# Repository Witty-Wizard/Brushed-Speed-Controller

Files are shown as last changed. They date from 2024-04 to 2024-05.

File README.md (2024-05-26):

<p align="center">
    
    
    
    
    
    
</p>

# Brushed Speed Controller

This project aims to create a Brushed Electronic Speed Controller (ESC) using KiCad. The ESC is designed to control the speed of a brushed DC motor using pulse-width modulation (PWM) signals.

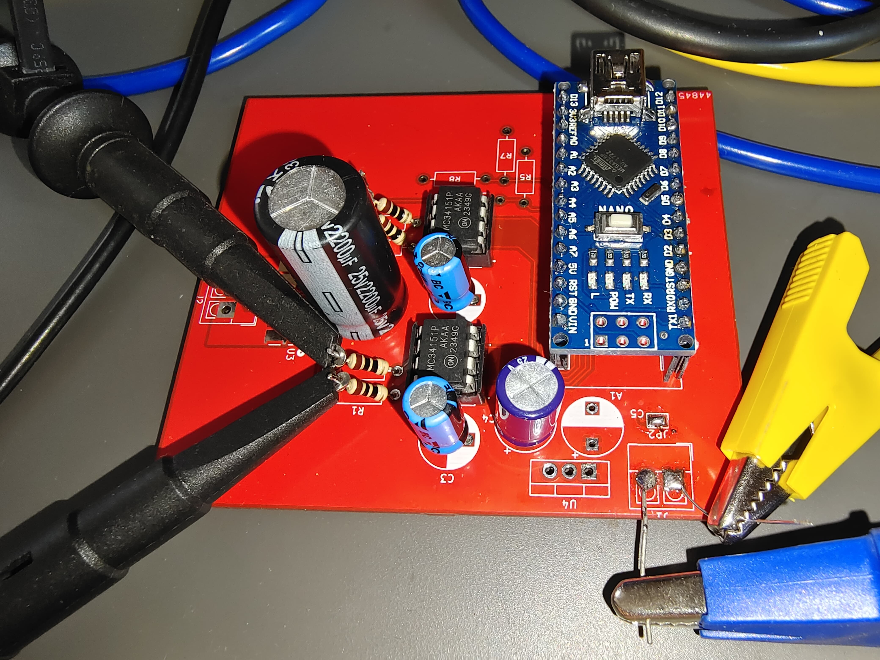
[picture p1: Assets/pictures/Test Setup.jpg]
Current Test Setup

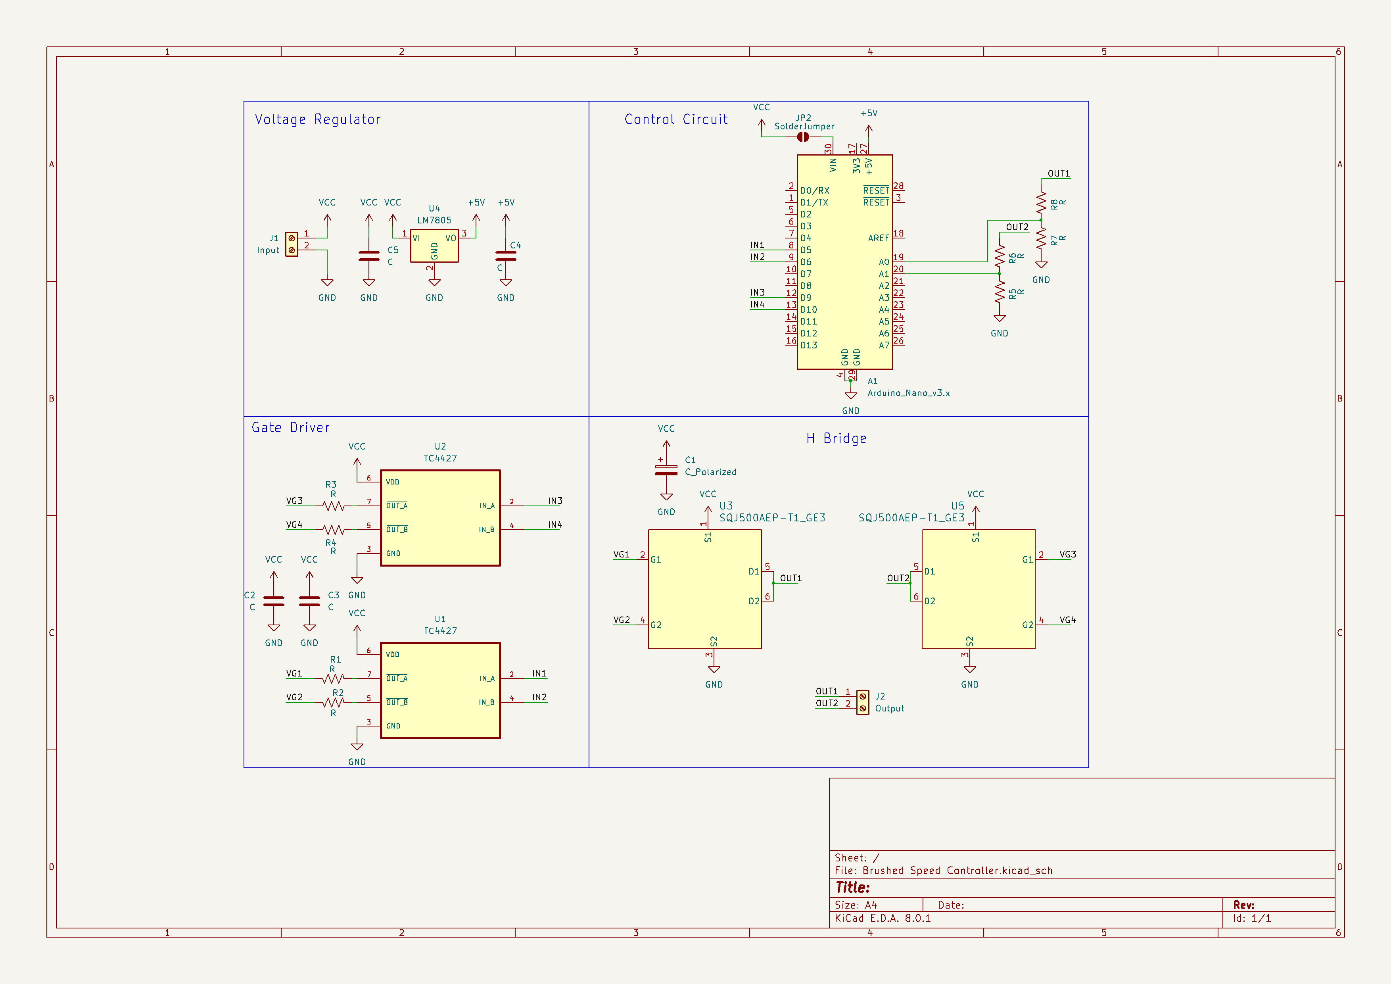
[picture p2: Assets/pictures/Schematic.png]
Schematic


## Components

### MOSFETs

- BSC340N08NS3
- ISC037N03L5ISATMA1

### Driver

- TC4427
- MC34151

### Arduino Nano

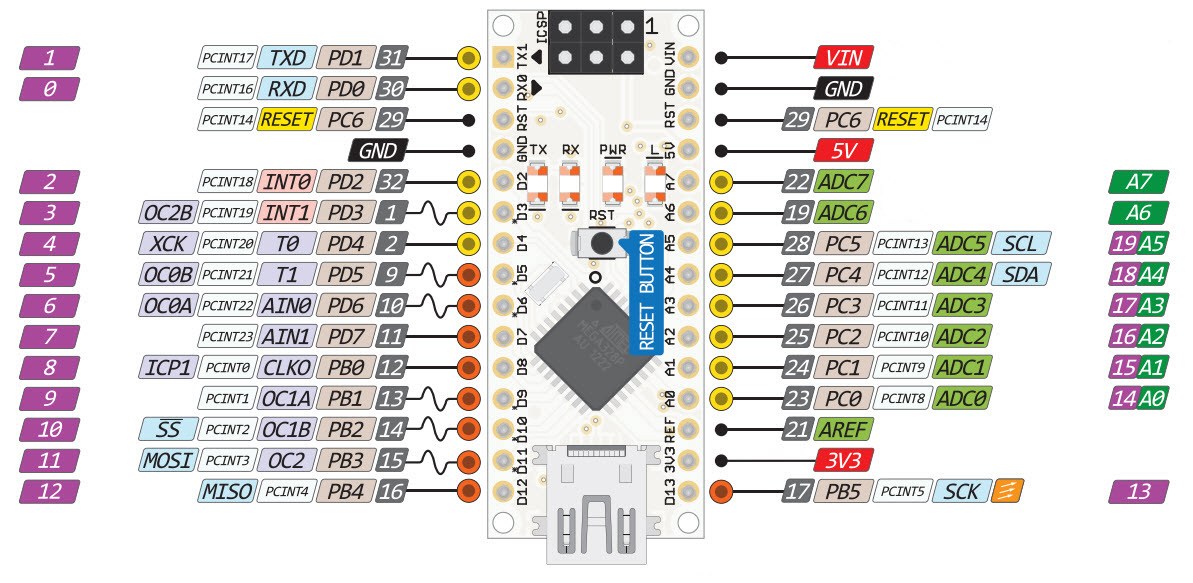
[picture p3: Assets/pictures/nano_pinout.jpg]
Arduino Pinout


### Output FSM

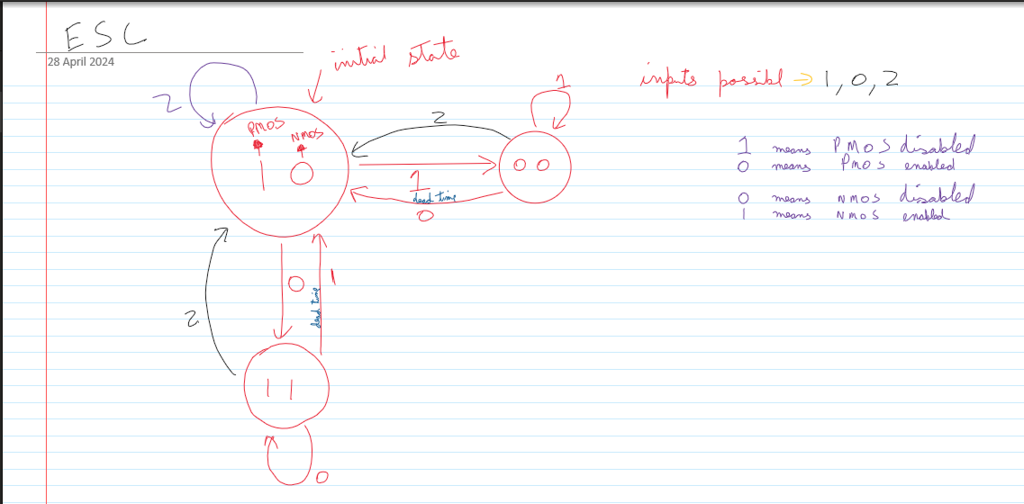
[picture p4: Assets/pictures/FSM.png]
Output side FSM logic


## Getting Started

To get started with this project, follow these steps:

1. Clone this repository to your local machine.

   ```bash
   git clone https://github.com/Witty-Wizard/Brushed-Speed-Controller.git
   ```

## License

This project is licensed under the GNU General Public License v3.0. You can find more details in the LICENSE file.

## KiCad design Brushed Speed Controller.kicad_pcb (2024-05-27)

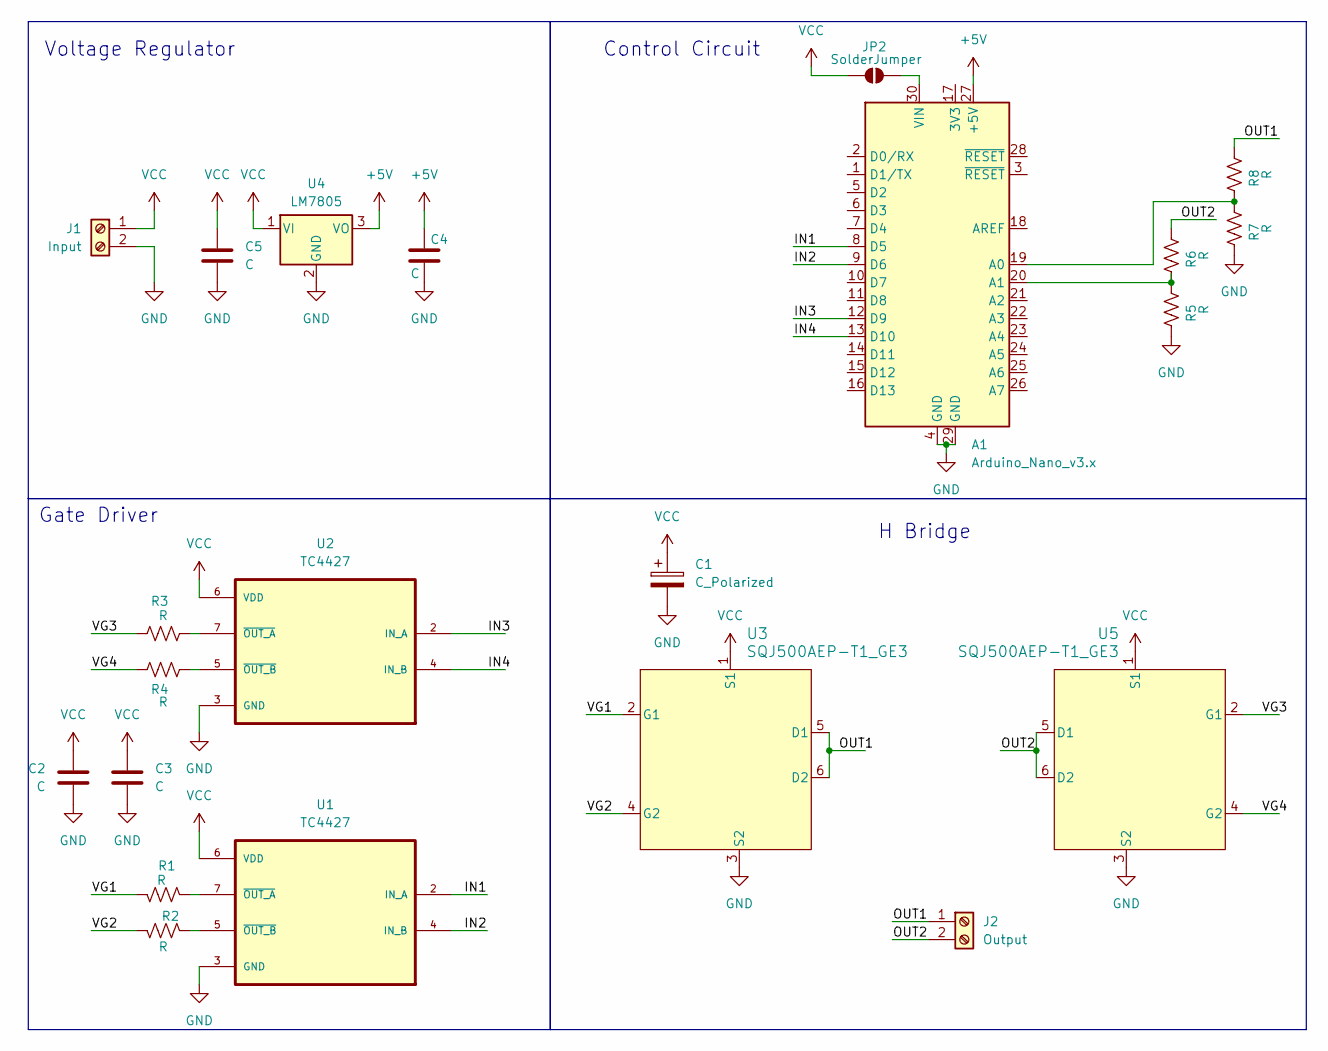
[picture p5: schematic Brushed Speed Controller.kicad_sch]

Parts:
A1: Arduino_Nano_v3.x; Arduino_Nano
C1: C_Polarized; CP_Radial_D8.0mm_P5.00mm
C2, C3, C4, C5: C; CP_Radial_D8.0mm_P5.00mm
J1: Input; TerminalBlock_bornier-2_P5.08mm
J2: Output; TerminalBlock_bornier-2_P5.08mm
JP2: SolderJumper; SolderJumper-2_P1.3mm_Open_TrianglePad1.0x1.5mm
R1, R2, R3, R4, R5, R6, R7, R8: R; R_Axial_DIN0207_L6.3mm_D2.5mm_P10.16mm_Horizontal
U1, U2: TC4427; PARTREV LTR
U3, U5: SQJ500AEP-T1_GE3; SQJ500AEP-T1-GE3
U4: LM7805; TO-220-3_Vertical

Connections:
+5V: A1.27 (+5V), C4.1, U4.3 (VO)
/IN1: A1.8 (D5), U1.2 (IN_A)
/IN2: A1.9 (D6), U1.4 (IN_B)
/IN3: A1.12 (D9), U2.2 (IN_A)
/IN4: A1.13 (D10), U2.4 (IN_B)
/OUT1: J2.1, R8.2, U3.5 (D1), U3.6 (D2)
/OUT2: J2.2, R6.2, U5.5 (D1), U5.6 (D2)
/VG1: R1.2, U3.2 (G1)
/VG2: R2.2, U3.4 (G2)
/VG3: R3.1, U5.2 (G1)
/VG4: R4.1, U5.4 (G2)
GND: A1.4 (GND), A1.29 (GND), C1.2, C2.2, C3.2, C4.2, C5.2, J1.2, R5.1, R7.1, U1.3 (GND), U2.3 (GND), U3.3 (S2), U4.2 (GND), U5.3 (S2)
unnamed: A1.19 (A0), R7.2, R8.1
unnamed: A1.20 (A1), R5.2, R6.1
unnamed: A1.30 (VIN), JP2.2 (B)
unnamed: R1.1, U1.7 (~OUT_A)
unnamed: R2.1, U1.5 (~OUT_B)
unnamed: R3.2, U2.7 (~OUT_A)
unnamed: R4.2, U2.5 (~OUT_B)
VCC: C1.1, C2.1, C3.1, C5.1, J1.1, JP2.1 (A), U1.6 (VDD), U2.6 (VDD), U3.1 (S1), U4.1 (VI), U5.1 (S1)

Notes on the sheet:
Voltage Regulator
H Bridge
Gate Driver
Control Circuit

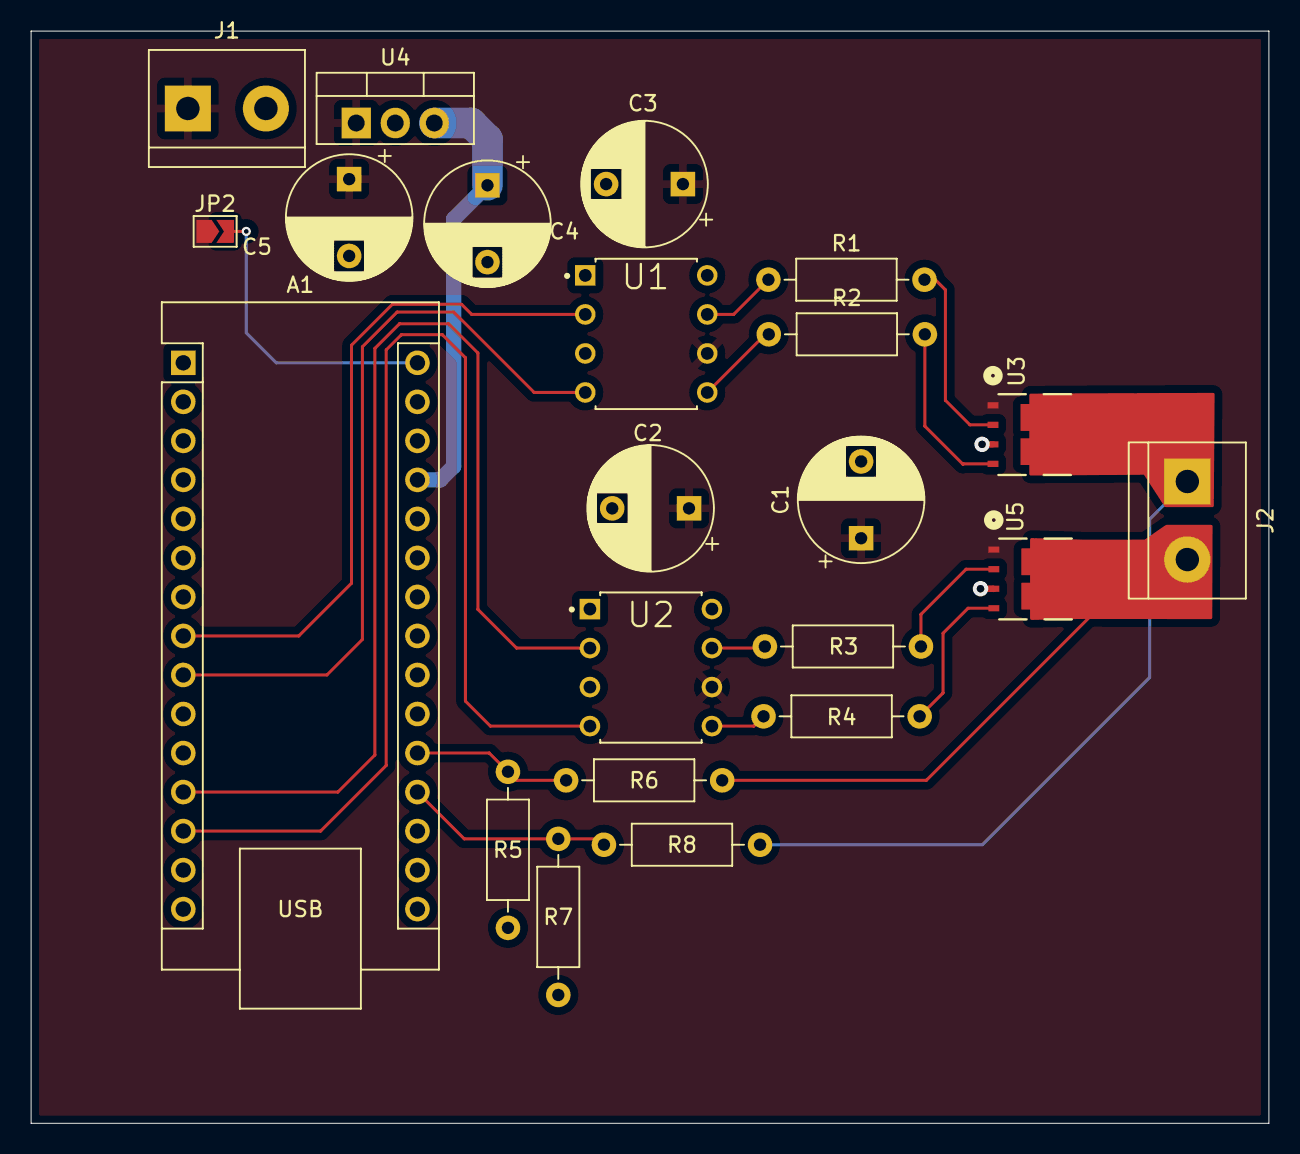
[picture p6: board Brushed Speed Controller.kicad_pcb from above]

Board: 2 copper layers, 80.6 x 71.1 mm, 22 parts (0 on the bottom side), 20 nets.

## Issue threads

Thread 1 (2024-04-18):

Use complementary P and N Mosfet for brushed ESC

Witty-Wizard, 2024-04-18:
Use the complementary N and P MOSFETs available in the SQJ500AEP-T1_GE3 for the brushed ESC design.

Witty-Wizard, 2024-04-18:
https://github.com/Witty-Wizard/Brushed-Speed-Controller/commit/bb878c7fc1ba5f598c44eacfe42a8b9dacc64ff8

Added the mosfet symbol in this commit, next need to add arduino Nano footprint

Witty-Wizard, 2024-04-25:
https://github.com/Witty-Wizard/Brushed-Speed-Controller/commit/e62d8913a873fe9dd3966c9efc68bd3aa09c23e9
@anshchawla521 Check this updated PCB

Witty-Wizard, 2024-05-26:
PCB approved by @anshchawla521 🥳🥳

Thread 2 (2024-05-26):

Use 2.54 mm Footprint of PCB terminal.

anshchawla521, 2024-05-26:
Either use 2.54 mm footprint for PCB terminal or add footprint for Xt-60.

Witty-Wizard, 2024-05-27:
https://github.com/Witty-Wizard/Brushed-Speed-Controller/commit/a9986da4f75f14f337d17ce60b3ca8d79011ef92

Closed 2024-05-27.

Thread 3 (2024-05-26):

Use of timer 0 on pin 5 ,6

anshchawla521, 2024-05-26:
Since pin 5, 6 are used for on side of h bridge we only get an 8 bit resolution since the timer 0 only supports that. This may be something to keep in mind when assigning pins for BB51

Witty-Wizard, 2024-05-27:
> Since pin 5, 6 are used for on side of h bridge we only get an 8 bit resolution since the timer 0 only supports that. This may be something to keep in mind when assigning pins for BB51

In BB51 all timers are 16-bit so no issues there

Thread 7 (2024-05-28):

🪲[Bug]: The mosfet Foot print is wrong

anshchawla521, 2024-05-28:
**Describe the bug**
The mosfet Foot print is wrong the NMOS connections are connected to PMOS and the Pmos connections are connected to NMOS

**To Reproduce**
Steps to reproduce the behavior:
NA

**Expected behavior**
NA

**Screenshots**
NA

**Desktop (please complete the following information):**
NA

**Smartphone (please complete the following information):**
NA

**Additional context**
NA

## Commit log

2024-04-16 Made H bridge
    [Brushed Speed Controller.kicad_pcb, Brushed Speed Controller.kicad_sch]
2024-04-16 added mosfet Driver
    [Brushed Speed Controller.kicad_sch]
2024-04-16 fixed symbol load issue
    [Brushed Speed Controller.kicad_pcb, Brushed Speed Controller.kicad_sch]
2024-04-17 Made first prototype PCB
    [Brushed Speed Controller.kicad_pcb, Brushed Speed Controller.kicad_sch]
2024-04-18 made symbol for mosfet
    [Brushed Speed Controller.kicad_pcb, Brushed Speed Controller.kicad_sch]
2024-04-23 Completed the PCB and Schemetic
    [Brushed Speed Controller.kicad_pcb, Brushed Speed Controller.kicad_sch]
2024-04-24 Added 7805 to schematic
    [Brushed Speed Controller.kicad_sch]
2024-04-25 Added L7805 to PCB
    [Brushed Speed Controller.kicad_pcb, Brushed Speed Controller.kicad_sch]
2024-04-25 Added Output files
    [Brushed Speed Controller-B_Cu.gbr, Brushed Speed Controller-B_Mask.gbr, Brushed Speed Controller-B_Paste.gbr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]
2024-05-26 Added First Test Code which Should Work
    [Brushed Speed Controller-B_Cu.gbr, Brushed Speed Controller-B_Mask.gbr, Brushed Speed Controller-B_Paste.gbr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]
2024-05-27 added kicad workflow
2024-05-27 pcb files in this directory
    [Brushed Speed Controller-B_Cu.gbr, Brushed Speed Controller-B_Mask.gbr, Brushed Speed Controller-B_Paste.gbr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]
2024-05-27 export gerber using actions
2024-05-27 added drill files
2024-05-27 Added bigger terminals
    [Brushed Speed Controller.kicad_pcb, Brushed Speed Controller.kicad_sch]
